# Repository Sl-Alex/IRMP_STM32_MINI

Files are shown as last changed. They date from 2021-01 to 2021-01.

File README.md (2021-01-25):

# IRMP Mini Board

This repository contains both PCB and case for IRMP project.
IRMP stands for "**I**nfra**R**ed **M**ulti**P**rotocol decoder".
This board is for STM32 port, which is developed by [Jörg Riechardt][1] and slightly modified (mostly pin assignments) by me.

## Assembly

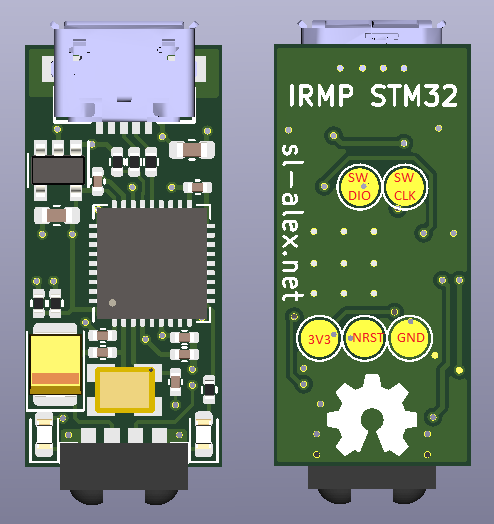
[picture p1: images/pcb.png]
Assembly preview


## Schematic

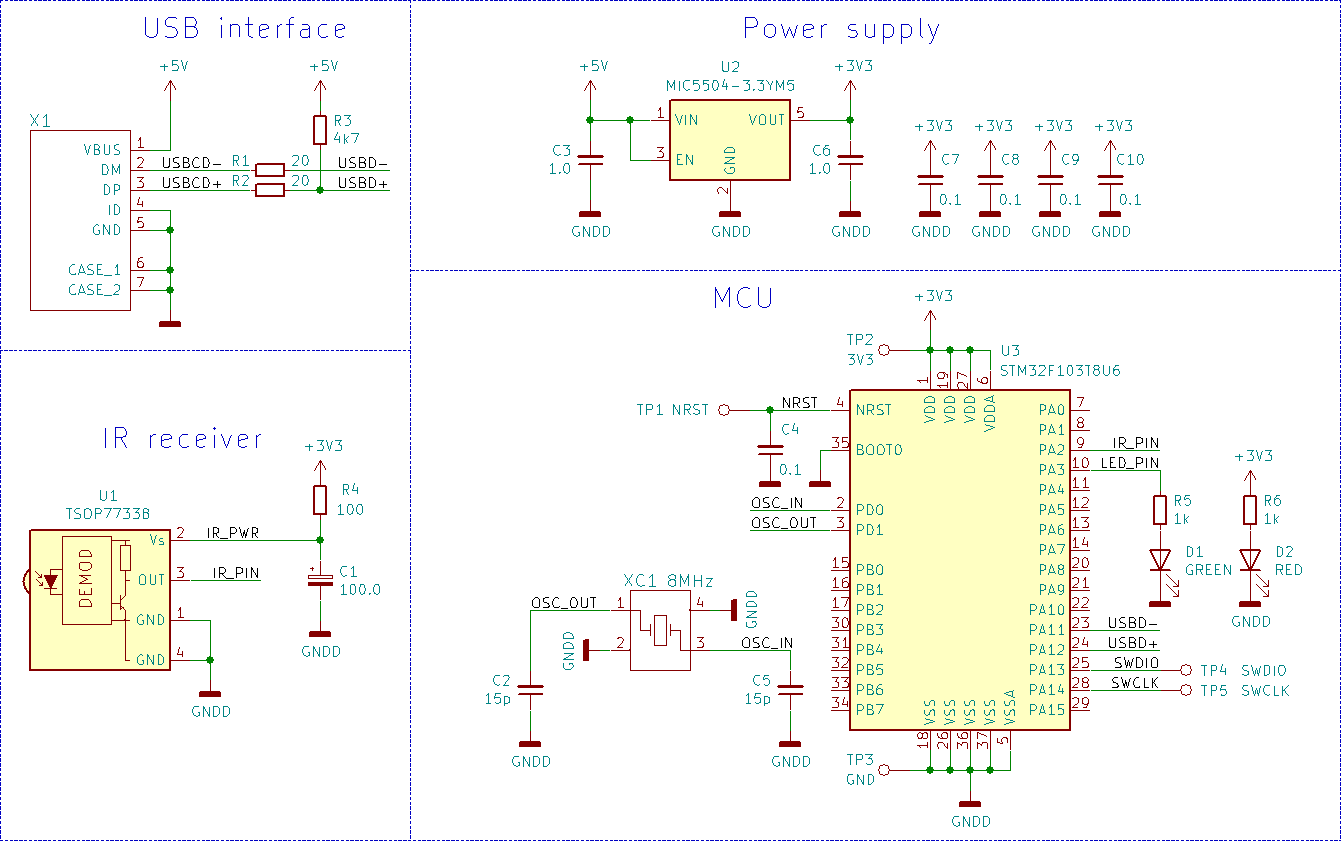
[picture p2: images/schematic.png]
Schematic


## Components

As you see, there are not too much components. In fact, the board can be assembled in about half an hour or less, depending on your soldering skills. Please be aware that the smallest components are in size 0402, which is still perfectly solderable, although may require some practice and patience. This is done intentionally to keep the size small.

Here is a list of components to order:

|Reference | Quantity | Value | Footprint | Remark |
| --- | --- | --- | --- | --- |
| C1 | 1 | 100.0µ | Case B | Tantalum capacitor |
| C2 C5 | 2 | 15p | 0402 | |
| C3 C6 | 2 | 1.0u | 0603 | |
| C4 C7 C8 C9 C10 | 5 | 0.1u | 0402 | |
| D1 | 1 | GREEN | 0603 | |
| D2 | 1 | RED | 0603 | |
| R1 R2 | 2 | 20 | 0402 | |
| R3 | 1 | 4k7 | 0402 | |
| R4 | 1 | 100 | 0402 | |
| R5 R6 | 2 | 1k | 0402 | |
| U1 | 1 | TSOP77338 | Heimdall | Vishay Heimdall package |
| U2 | 1 | MIC5504-3.3YM5  | SOT-23-5 | |
| U3 | 1 | STM32F103T8U6 | VFQFPN-36 | |
| X1 | 1 | 10118192-0001LF | USB2_MICRO_B | Most common USB micro B package. 10118192-0001LF from Amphenol ICC (FCI) fits perfectly |
| XC1 | 1 | 8MHz | 3225 | 4 pin passive crystal in SMD 3225 package |

## HowTo

- Order all components or make sure they are available
- Order the board. Gerbers are [here][2]
- Solder the board. I'd suggest soldering USB connector and power supply part first, checking if it works and then soldering the rest
- Download DFU bootloader [here][3]
- Flash the DFU bootloader using your favourite SWD adapter. Pin assignments are in the [assembly section](#assembly).
- Connect the board. It will be recognized as "STM32 Bootloader"
- Take the fw [here][4] (the most recent ```*IrmpMini_BL*.bin```)
- Run ```dfu-util -w -D <path_to_the_fw>```. DFU utility can be taken [here][5]
- Wait until the new FW is downloaded
- Reconnect the board

[pic_assembly]: images/pcb.png
[pic_schematic]: images/schematic.png

[1]: https://github.com/j1rie
[2]: https://github.com/Sl-Alex/IRMP_STM32_MINI/tree/main/plots
[3]: https://github.com/Sl-Alex/STM32F103-bootloader/raw/master/binaries/boot.IrmpMini.bin
[4]: https://github.com/Sl-Alex/IRMP_STM32/tree/master/binaries/firmware_for_bootloader
[5]: https://github.com/Sl-Alex/IRMP_STM32/tree/master/binaries/bootloader

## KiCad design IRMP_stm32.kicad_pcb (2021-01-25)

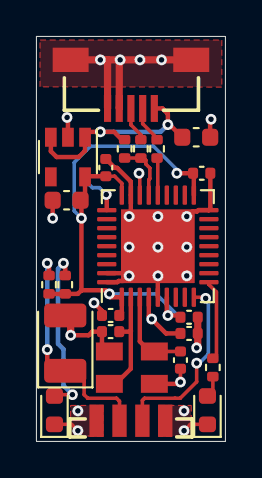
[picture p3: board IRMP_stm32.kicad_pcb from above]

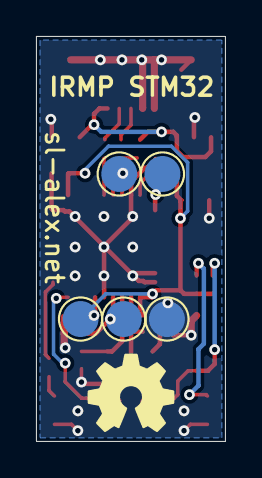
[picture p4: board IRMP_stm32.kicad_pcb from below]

Board: 2 copper layers, 10.5 x 22.5 mm, 29 parts (6 on the bottom side), 17 nets.

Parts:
C1: 100.0; CP_EIA-3528-21_Kemet-B
C2, C5: 15p; C_0402_1005Metric
C3, C6: 1.0; C_0603_1608Metric
C4, C7, C8, C9, C10: 0.1; C_0402_1005Metric
D1: GREEN; LED_0603_1608Metric
D2: RED; LED_0603_1608Metric
LG?1: LOGO; OSHW
R1, R2: 20; R_0402_1005Metric
R3: 4k7; R_0402_1005Metric
R4: 100; R_0402_1005Metric
R5, R6: 1k; R_0402_1005Metric
TP1: NRST; TestPoint_Pad_D2.0mm
TP2: 3V3; TestPoint_Pad_D2.0mm
TP3: GND; TestPoint_Pad_D2.0mm
TP4: SWDIO; TestPoint_Pad_D2.0mm
TP5: SWCLK; TestPoint_Pad_D2.0mm
U1: TSOP77338; Vishay_Heimdall
U2: MIC5504-3.3YM5; SOT-23-5
U3: STM32F103T8U6; QFN-36-1EP_6x6mm_P0.5mm_EP4.1x4.1mm
X1: 10118192-0001LF; USB2_MICRO_B_F1
XC1: 8MHz; SMD_3225

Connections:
+3V3: C6.2, C7.2, C8.2, C9.2, C10.2, R4.2, R6.2, TP2.1, U2.5, U3.1, U3.6, U3.19, U3.27
+5V: C3.2, R3.2, U2.1, U2.3, X1.1
/IR_PIN: U1.3, U3.9
/IR_PWR: C1.1, R4.1, U1.2
/LED_PIN: R5.2, U3.10
/NRST: C4.2, TP1.1, U3.4
/OSC_IN: C5.2, U3.2, XC1.3
/OSC_OUT: C2.2, U3.3, XC1.1
/SWCLK: TP5.1, U3.28
/SWDIO: TP4.1, U3.25
/USBCD+: R2.2, X1.3
/USBCD-: R1.2, X1.2
/USBD+: R2.1, R3.1, U3.24
/USBD-: R1.1, U3.23
GNDD: C1.2, C2.1, C3.1, C4.1, C5.1, C6.1, C7.1, C8.1, C9.1, C10.1, D1.1, D2.1, TP3.1, U1.1, U1.4, U2.2, U3.5, U3.18, U3.26, U3.35, U3.36, U3.37, X1.4, X1.5, X1.6, X1.7, XC1.2, XC1.4
unnamed: D1.2, R5.1
unnamed: D2.2, R6.1

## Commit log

2021-01-02 First prototype
    [IRMP_stm32.kicad_pcb, IRMP_stm32.sch]
2021-01-21 Connect crystal lid to GND
    [IRMP_stm32.kicad_pcb, IRMP_stm32.sch]
2021-01-22 Set crystal frequency to 8MHz
    [IRMP_stm32.kicad_pcb, IRMP_stm32.sch]
2021-01-22 Add Gerbers
    [IRMP_stm32-B_Cu.gbr, IRMP_stm32-B_Mask.gbr, IRMP_stm32-B_Paste.gbr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]
2021-01-25 Update component values
    [IRMP_stm32.kicad_pcb, IRMP_stm32.sch]
